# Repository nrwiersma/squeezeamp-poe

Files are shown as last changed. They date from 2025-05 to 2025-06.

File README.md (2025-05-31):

# SqueezeAMP PoE




`SqueezeAMP PoE` is an amplifier driven by an ESP32 designed to run [squeezelite-esp32](https://github.com/sle118/squeezelite-esp32), powered by PoE++.

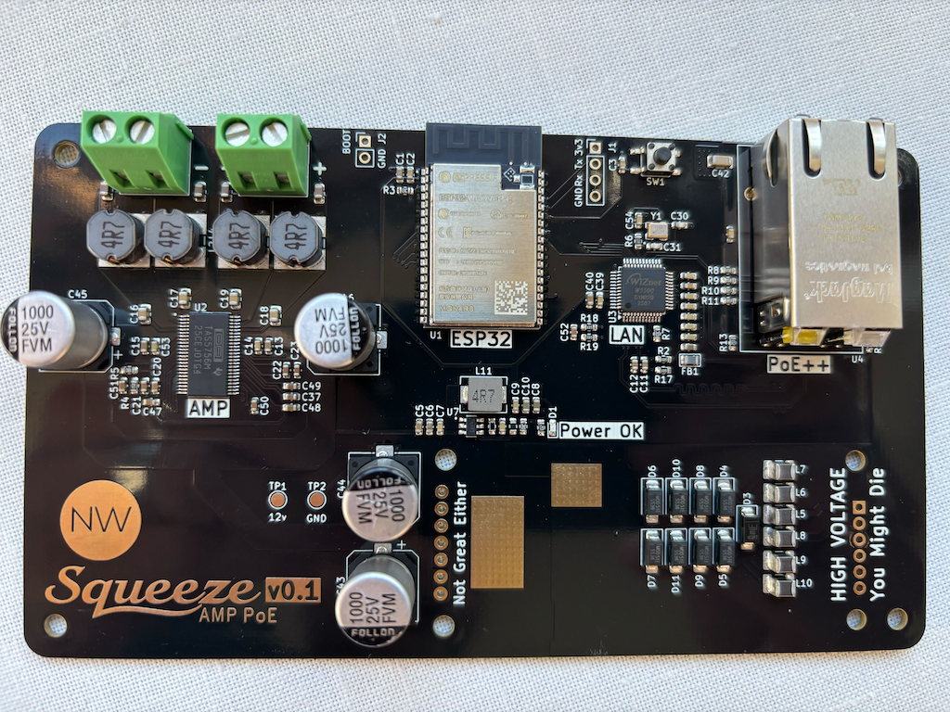
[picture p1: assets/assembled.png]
board image


Features:

* Power over Ethernet 802.3bt 60W (PoE++)
* ESP32 WROOM 4MB Flash 8MB PSRAM
* TAS5756 Amplifier capable of driving stereo 30W 8Ohm speakers

## Why

The position of speakers is often not optimal for WiFi, leading to unreliable music streaming. Adding 100Mb ethernet allows
more reliable connections with ample bandwidth. Given an ethernet connection, PoE is able to provide power for the device.

The schematic is inspired by the [SqueezeAMPagain](https://github.com/hallo-alex/SqueezeAMPagain).

## Configuration

Install [squeezelite-esp32](https://github.com/sle118/squeezelite-esp32). The simplest method is to use the [installer](https://sle118.github.io/squeezelite-esp32-installer/).

Set the following configuration via the NVS Editor to configure:

dac_config: `model=TAS57xx,bck=33,ws=25,do=32,sda=27,scl=26,mute=4:0`
eth_config: `model=w5500,cs=15,speed=20000000,intr=18,rst=19`
spi_config: `mosi=13,clk=14,host=1,miso=12,dc=-1`
set_GPIO:   `2=spkfault`

## PCB Fabrication and Assembly by PCBWay

I am proudly sponsored by [PCBWay](https://www.pcbway.com/), a leading manufacturer specializing in PCB prototyping, 
low-volume production, and PCB Assembly services. Thanks to PCBWay’s sponsorship, I was able to fabricate and assemble 
my PCBs with high precision and quality. Their advanced manufacturing capabilities ensured that our design was 
translated into a robust and functional product.

[//]: # (![board image]&#40;assets/pcb.png&#41;)

### Why PCBWay?

PCBWay offers:

* **High-quality PCB fabrication** with multiple layer options, surface finishes, and material choices.
* **Fast turnaround times** to meet project deadlines efficiently.
* **Affordable pricing** for both prototyping and mass production.
* **Reliable PCB assembly services**, including SMT, through-hole, and mixed assembly.
* **Exceptional customer support** and a user-friendly ordering platform.

### Get Your Own PCBs from PCBWay

I highly recommend PCBWay for all your PCB fabrication and assembly needs. Their dedication to quality and customer 
satisfaction makes them an ideal partner for your projects. If you're looking for a trusted partner for PCB fabrication 
and assembly, check out PCBWay for your next project.

Special thanks to PCBWay for their generous support!

## Changelog

#### v0.1.0

* Initial schematic and board

#### v0.1.1

* Fixed W5500 crystal clock not being enabled

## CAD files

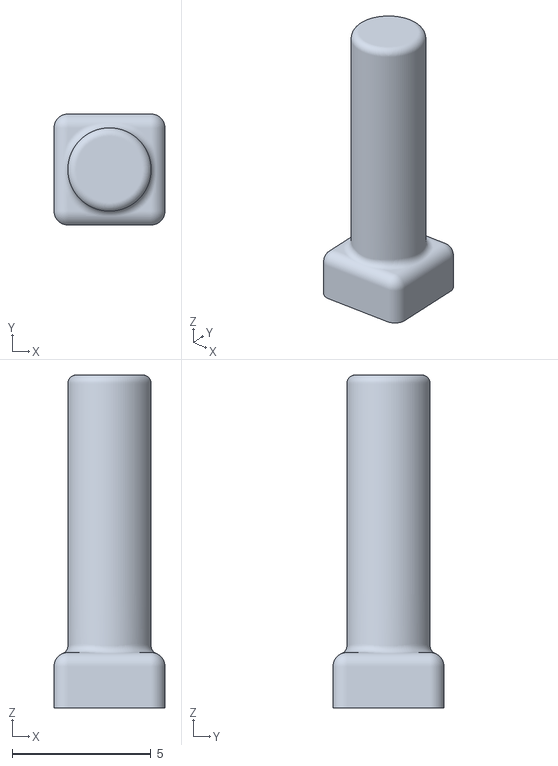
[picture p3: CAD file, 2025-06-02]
models/Button.stl
4.00 x 4.00 x 12.0

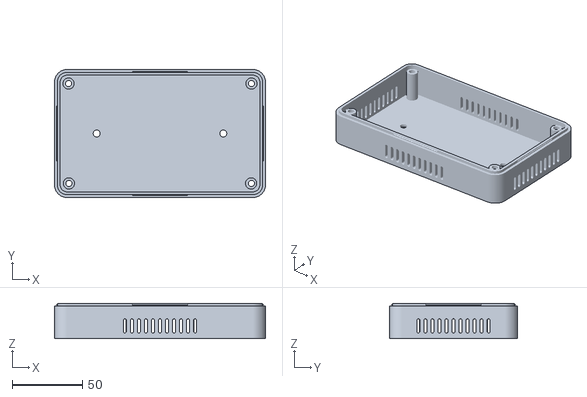
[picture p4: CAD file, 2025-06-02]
models/Base.stl
150.0 x 91.0 x 25.0

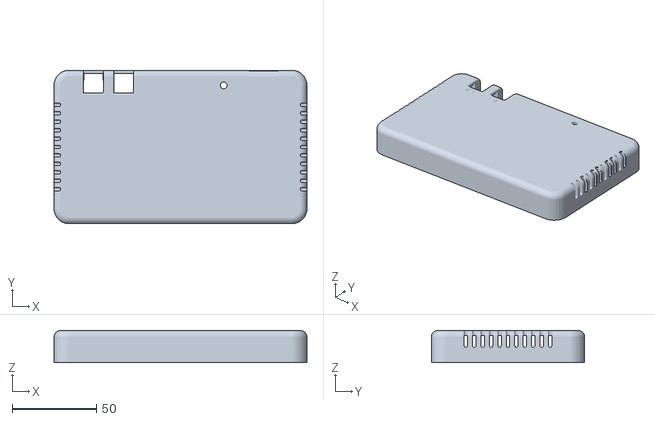
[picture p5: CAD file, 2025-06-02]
models/Lid.stl
150.0 x 91.0 x 19.0

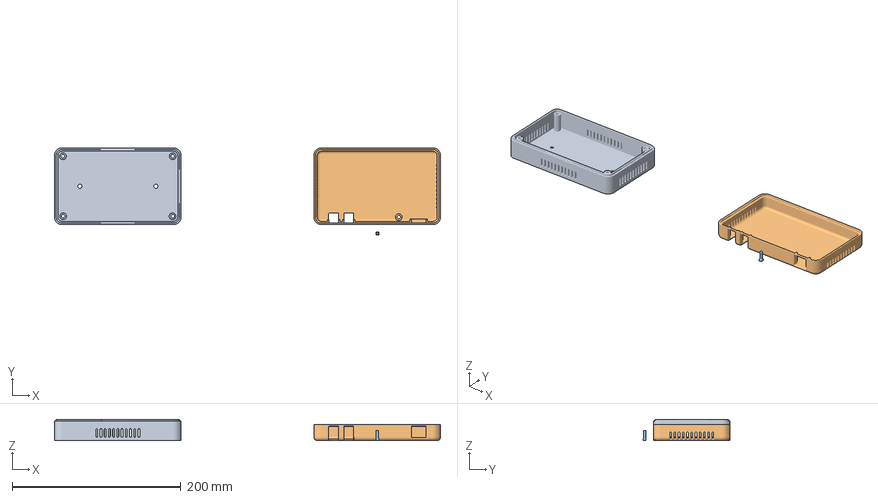
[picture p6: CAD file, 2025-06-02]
models/SqueezeAMPPoE.3mf
457.2 x 103.4 x 25.0 mm
Base.stl
Lid.stl
Button.stl

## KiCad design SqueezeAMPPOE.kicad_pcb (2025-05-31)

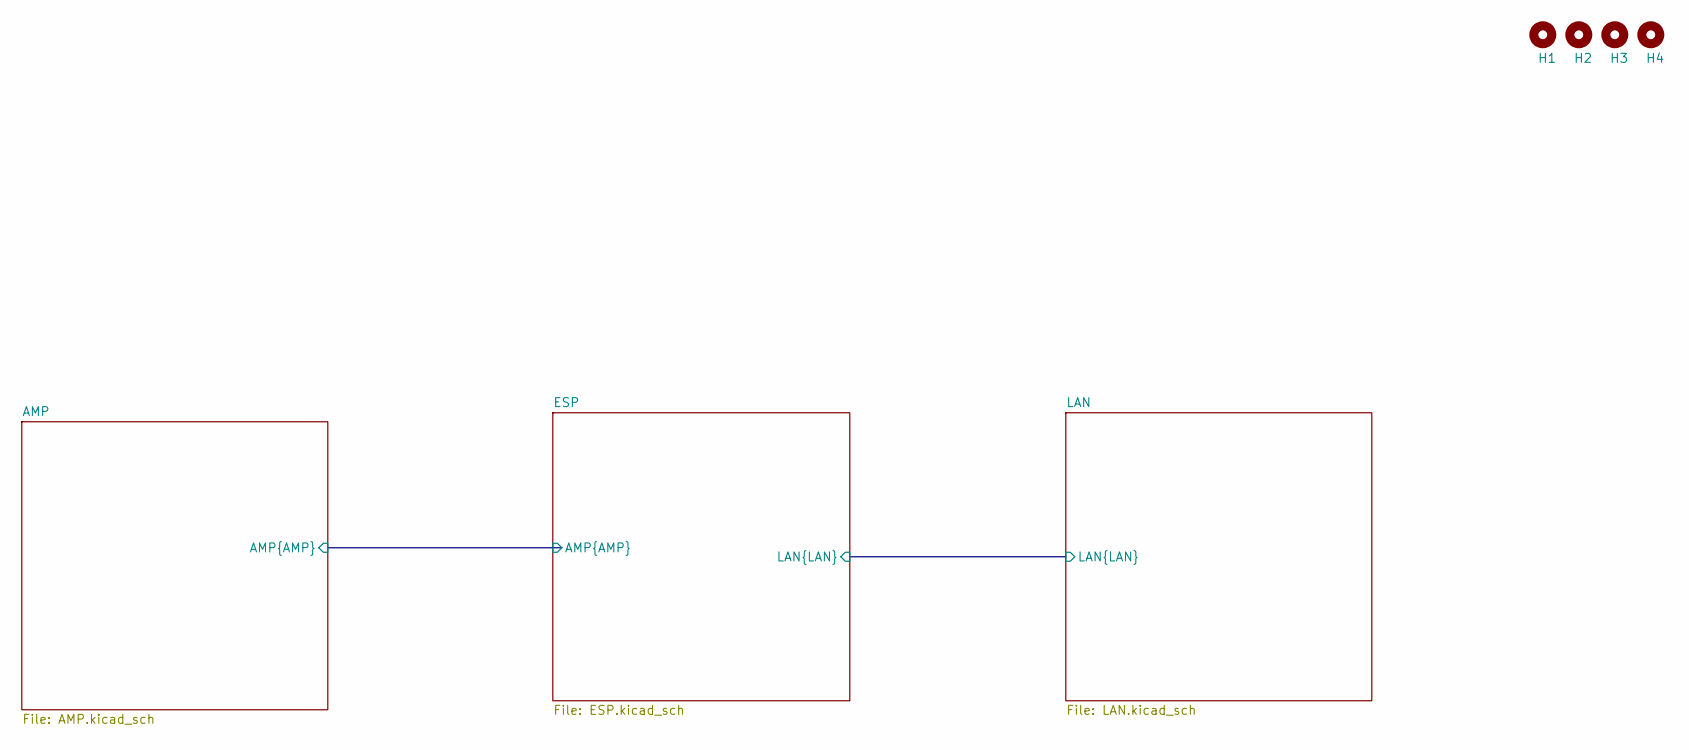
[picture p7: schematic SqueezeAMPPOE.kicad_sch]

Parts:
H1, H2, H3, H4: MountingHole; MountingHole_3.2mm_M3

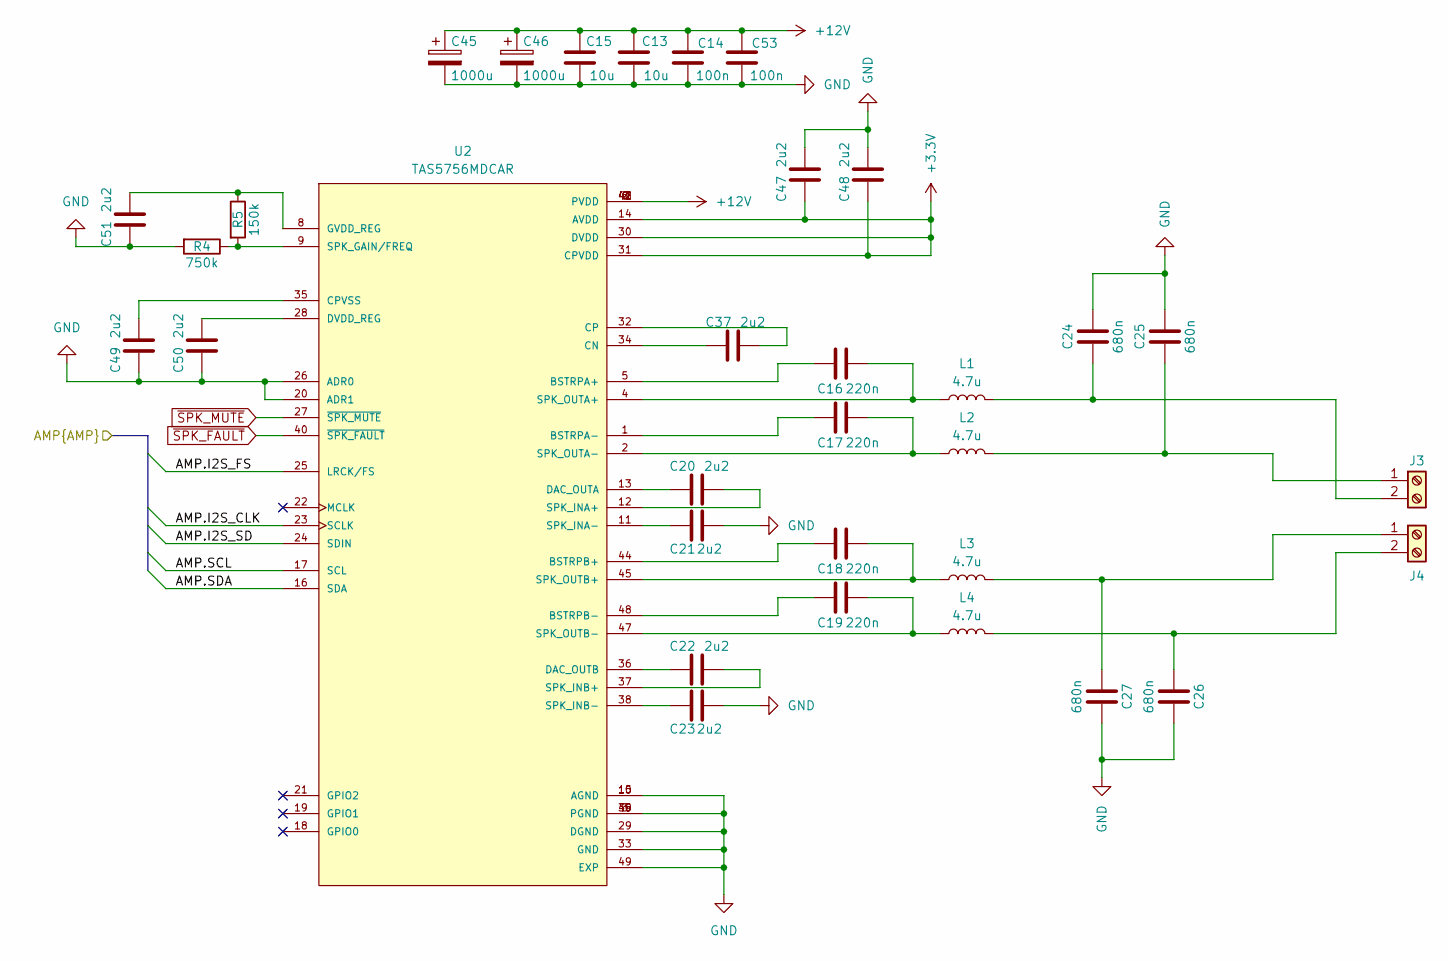
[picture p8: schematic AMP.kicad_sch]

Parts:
C13, C15: 10u; C_0603_1608Metric; MPN CL10A106MA8NRNC; JLCPCB Part # C96446
C14, C53: 100n; C_0603_1608Metric; MPN CL10B104KB8NNNC; JLCPCB Part # C1591
C16, C17, C18, C19: 220n; C_0805_2012Metric; MPN CL21B224KBFNNNE; JLCPCB Part # C5378
C20, C21, C22, C23, C37, C47, C48, C49, C50, C51: 2u2; C_0603_1608Metric; MPN CL10A225KA8NNNC; JLCPCB Part # C57895
C24, C25, C26, C27: 680n; C_0805_2012Metric; MPN CC0805KKX7R9BB684; JLCPCB Part # C107133
C45, C46: 1000u; CP_Elec_10x12.5; MPN EFVM025ADA102M10C0; JLCPCB Part # C22387800
J3, J4: Screw_Terminal_01x02; TerminalBlock_Phoenix_MKDS-1,5-2-5.08_1x02_P5.08mm_Horizont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; MPN 1715721; JLCPCB Part # C480516
L1, L2, L3, L4: 4.7u; L_Ferrocore_DLG-0703; MPN SM7850-4R7MT; JLCPCB Part # C52377
R4: 750k; R_0603_1608Metric; MPN RC0603FR-07750KL; JLCPCB Part # C137684
R5: 150k; R_0603_1608Metric; MPN RC0603FR-07150KL; JLCPCB Part # C114660
U2: TAS5756MDCAR; SOP50P810X120-49N; MPN TAS5756MDCAR; JLCPCB Part # C2867541

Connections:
+3.3V: C47.1, C48.1, U2.14 (AVDD), U2.30 (DVDD), U2.31 (CPVDD); also elsewhere on the board
+12V: C13.2, C14.2, C15.2, C45.1, C46.1, C53.2, U2.6 (PVDD), U2.7 (PVDD), U2.41 (PVDD), U2.42 (PVDD), U2.43 (PVDD); also elsewhere on the board
/AMP/AMP.I2S_CLK: U2.23 (SCLK); also elsewhere on the board
/AMP/AMP.I2S_FS: U2.25 (LRCK/FS); also elsewhere on the board
/AMP/AMP.I2S_SD: U2.24 (SDIN); also elsewhere on the board
/AMP/AMP.SCL: U2.17 (SCL); also elsewhere on the board
/AMP/AMP.SDA: U2.16 (SDA); also elsewhere on the board
GND: C13.1, C14.1, C15.1, C21.2, C23.2, C24.2, C25.2, C26.2, C27.2, C45.2, C46.2, C47.2, C48.2, C49.1, C50.1, C51.1, C53.1, R4.2, U2.3 (PGND), U2.10 (AGND), U2.15 (AGND), U2.20 (ADR1), U2.26 (ADR0), U2.29 (DGND), U2.33 (GND), U2.39 (PGND), U2.46 (PGND), U2.49 (EXP); also elsewhere on the board
unnamed: C25.1, J3.1, L2.2
unnamed: C24.1, J3.2, L1.2
unnamed: C27.1, J4.1, L3.2
unnamed: C26.1, J4.2, L4.2
unnamed: C16.1, U2.5 (BSTRPA+)
unnamed: C17.1, U2.1 (BSTRPA-)
unnamed: C18.1, U2.44 (BSTRPB+)
unnamed: C19.1, U2.48 (BSTRPB-)
unnamed: C37.1, U2.34 (CN)
unnamed: C37.2, U2.32 (CP)
unnamed: C49.2, U2.35 (CPVSS)
unnamed: C20.1, U2.13 (DAC_OUTA)
unnamed: C22.1, U2.36 (DAC_OUTB)
unnamed: C50.2, U2.28 (DVDD_REG)
unnamed: C51.2, R5.1, U2.8 (GVDD_REG)
unnamed: R4.1, R5.2, U2.9 (SPK_GAIN/FREQ)
unnamed: C20.2, U2.12 (SPK_INA+)
unnamed: C21.1, U2.11 (SPK_INA-)
unnamed: C22.2, U2.37 (SPK_INB+)
unnamed: C23.1, U2.38 (SPK_INB-)
unnamed: C16.2, L1.1, U2.4 (SPK_OUTA+)
unnamed: C17.2, L2.1, U2.2 (SPK_OUTA-)
unnamed: C18.2, L3.1, U2.45 (SPK_OUTB+)
unnamed: C19.2, L4.1, U2.47 (SPK_OUTB-)
~SPK_FAULT: U2.40 (~SPK_FAULT); also elsewhere on the board
~SPK_MUTE: U2.27 (~SPK_MUTE); also elsewhere on the board

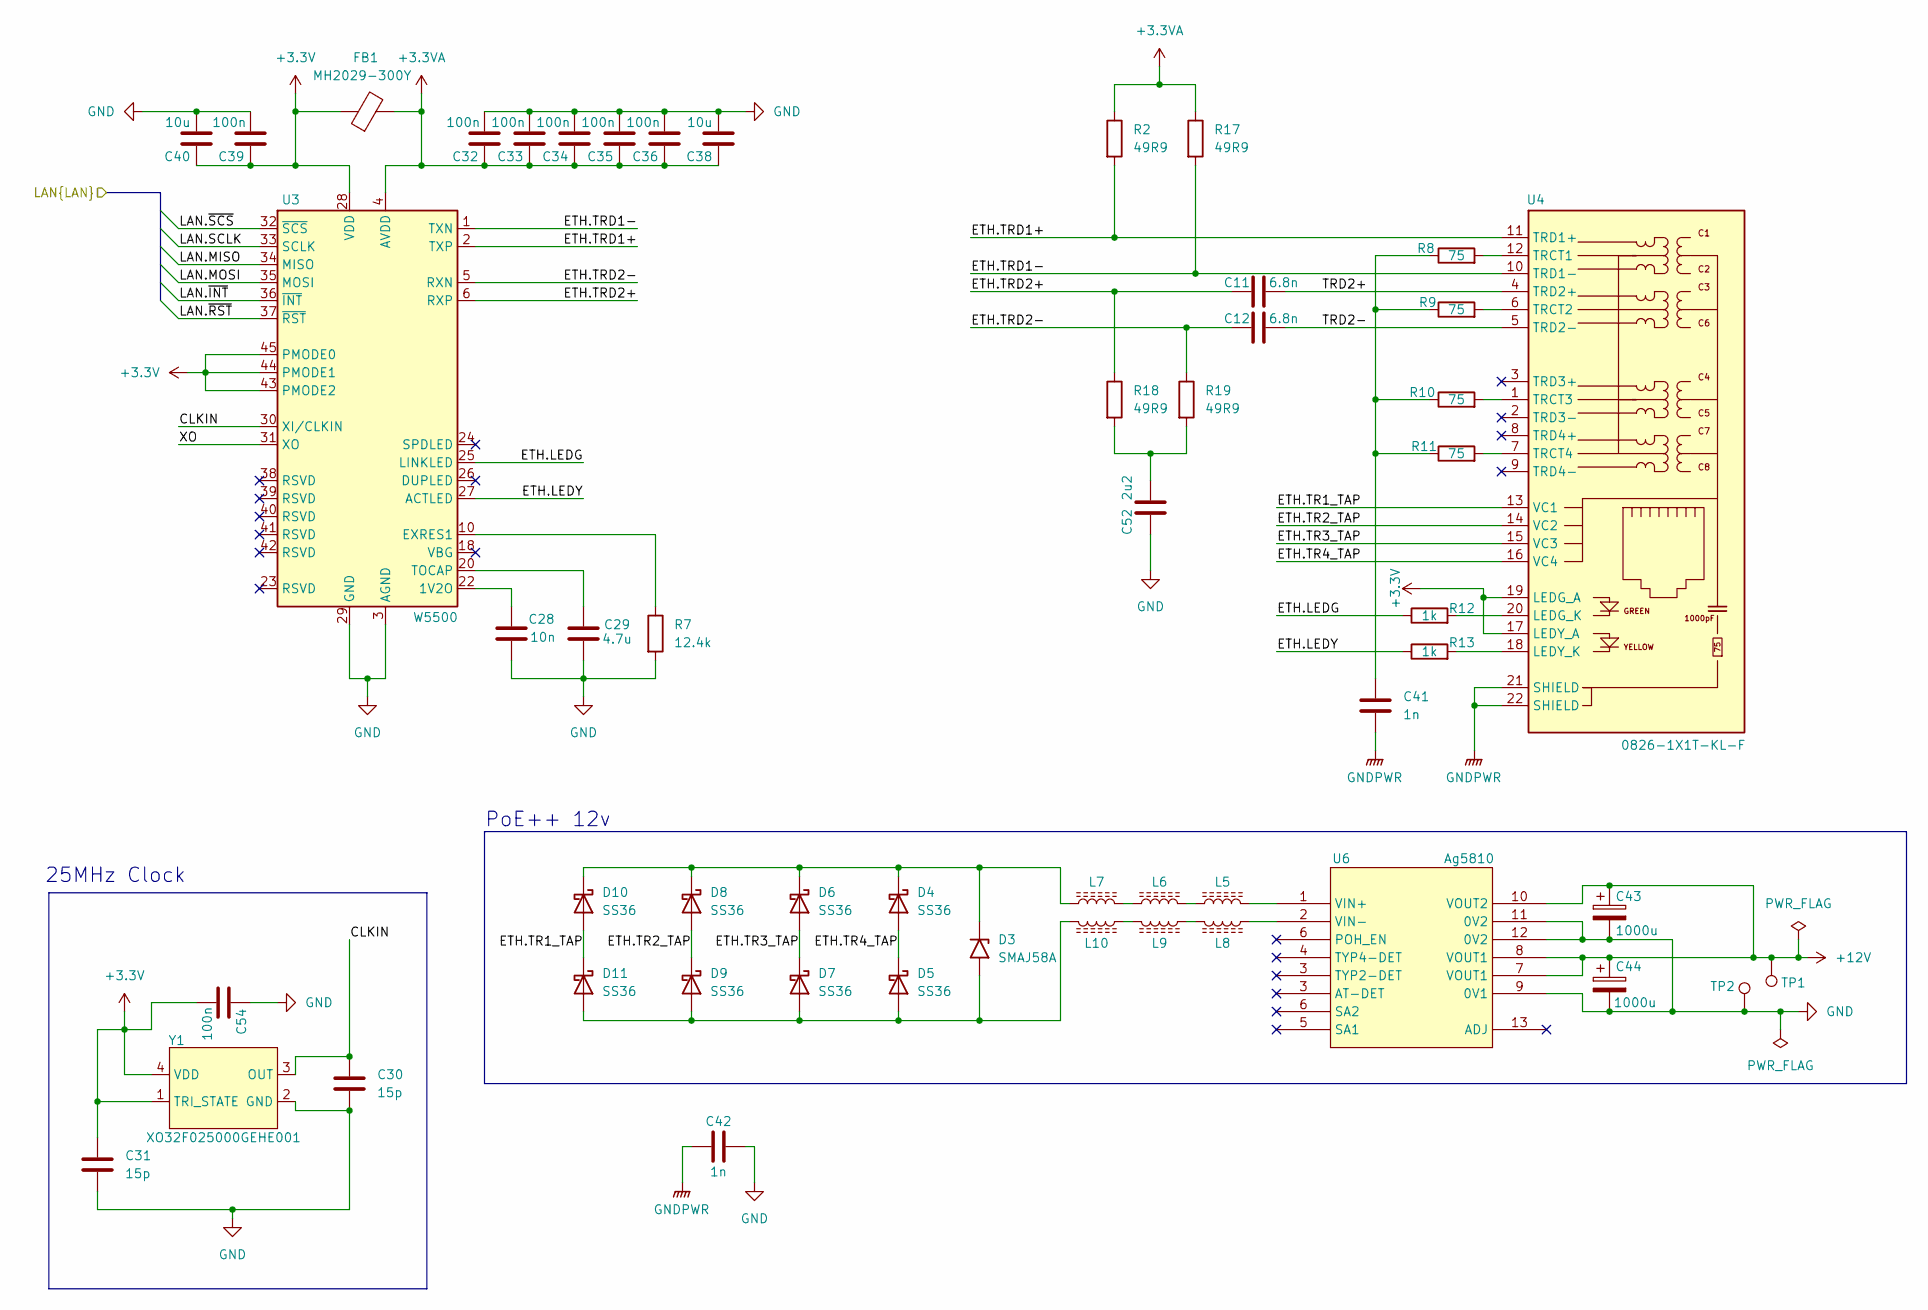
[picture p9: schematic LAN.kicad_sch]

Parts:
C11, C12: 6.8n; C_0603_1608Metric; MPN C1608C0G2A682J080AC; JLCPCB Part # C2183110
C28: 10n; C_0603_1608Metric; MPN CL10B103KB8NNNC; JLCPCB Part # C1589
C29: 4.7u; C_0603_1608Metric; MPN CL10A475KP8NNNC; JLCPCB Part # C1705
C30, C31: 15p; C_0603_1608Metric; MPN CL10C150JB8NNNC; JLCPCB Part # C1644
C32, C33, C34, C35, C36, C39, C54: 100n; C_0603_1608Metric; MPN CL10B104KB8NNNC; JLCPCB Part # C1591
C38, C40: 10u; C_0603_1608Metric; MPN CL10A106MA8NRNC; JLCPCB Part # C96446
C41: 1n; C_0603_1608Metric; MPN CL10B102KB8NNNC; JLCPCB Part # C1588
C42: 1n; C_1206_3216Metric; MPN CC1206KKX7RDBB102; JLCPCB Part # C23631
C43, C44: 1000u; CP_Elec_10x12.5; MPN EFVM025ADA102M10C0; JLCPCB Part # C22387800
C52: 2u2; C_0603_1608Metric; MPN CL10A225KA8NNNC; JLCPCB Part # C57895
D3: SMAJ58A; D_SMA; MPN SMAJ58A; JLCPCB Part # C151246
D4, D5, D6, D7, D8, D9, D10, D11: SS36; D_SMA; MPN SS36; JLCPCB Part # C16015
FB1: MH2029-300Y; L0805; MPN MH2029-300Y; JLCPCB Part # C840593
L5, L6, L7, L8, L9, L10: FBMH3225HM102NT; L_1210; MPN FBMH3225HM102NT; JLCPCB Part # C21520
R2, R17, R18, R19: 49R9; R_0603_1608Metric; MPN RC0603FR-0749R9L; JLCPCB Part # C114625
R7: 12.4k; R_0603_1608Metric; MPN RC0603FR-0712K4L; JLCPCB Part # C137798
R8, R9, R10, R11: 75; R_0603_1608Metric; MPN RC0603FR-0775RL; JLCPCB Part # C112309
R12, R13: 1k; R_0603_1608Metric; MPN RC0603JR-071KL; JLCPCB Part # C14676
TP1, TP2: TestPoint; TestPoint_Pad_D2.0mm
U3: W5500; LQFP-48_7x7mm_P0.5mm; MPN W5500; JLCPCB Part # C32843
U4: 0826-1X1T-KL-F; CONN_0826-1X1T-HS-F_BEL; MPN 0826-1X1T-KL-F; JLCPCB Part # C3179906
U6: Ag5810; Converter_DCDC_Silvertel_Ag5810; MPN Ag5810
Y1: XO32F025000GEHE001; SMD3225-4P; MPN XO32F025000GEHE001; JLCPCB Part # C20607963

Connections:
+3.3V: C31.2, C39.1, C40.1, C54.2, FB1.1, U3.28 (VDD), U3.43 (PMODE2), U3.44 (PMODE1), U3.45 (PMODE0), U4.17 (LEDY_A), U4.19 (LEDG_A), Y1.1 (TRI_STATE), Y1.4 (VDD); also elsewhere on the board
+3.3VA: C32.1, C33.1, C34.1, C35.1, C36.1, C38.1, FB1.2, R2.1, R17.1, U3.4 (AVDD), U3.8 (AVDD), U3.11 (AVDD), U3.15 (AVDD), U3.17 (AVDD), U3.21 (AVDD)
+12V: C43.1, C44.1, TP1.1, U6.7 (VOUT1), U6.8 (VOUT1), U6.10 (VOUT2); also elsewhere on the board
/ESP/LAN.MISO: U3.34 (MISO); also elsewhere on the board
/ESP/LAN.MOSI: U3.35 (MOSI); also elsewhere on the board
/ESP/LAN.SCLK: U3.33 (SCLK); also elsewhere on the board
/ESP/LAN.~INT: U3.36 (~INT); also elsewhere on the board
/ESP/LAN.~RST: U3.37 (~RST); also elsewhere on the board
/ESP/LAN.~SCS: U3.32 (~SCS); also elsewhere on the board
/LAN/CLKIN: C30.1, U3.30 (XI/CLKIN), Y1.3 (OUT)
/LAN/ETH.LEDG: R12.1, U3.25 (LINKLED)
/LAN/ETH.LEDY: R13.1, U3.27 (ACTLED)
/LAN/ETH.TR1_TAP: D10.2 (A), D11.1 (K), U4.13 (VC1)
/LAN/ETH.TR2_TAP: D8.2 (A), D9.1 (K), U4.14 (VC2)
/LAN/ETH.TR3_TAP: D6.2 (A), D7.1 (K), U4.15 (VC3)
/LAN/ETH.TR4_TAP: D4.2 (A), D5.1 (K), U4.16 (VC4)
/LAN/ETH.TRD1+: R2.2, U3.2 (TXP), U4.11 (TRD1+)
/LAN/ETH.TRD1-: R17.2, U3.1 (TXN), U4.10 (TRD1-)
/LAN/ETH.TRD2+: C11.1, R18.1, U3.6 (RXP)
/LAN/ETH.TRD2-: C12.1, R19.1, U3.5 (RXN)
/LAN/TRD2+: C11.2, U4.4 (TRD2+)
/LAN/TRD2-: C12.2, U4.5 (TRD2-)
/LAN/XO: U3.31 (XO)
GND: C28.2, C29.2, C30.2, C31.1, C32.2, C33.2, C34.2, C35.2, C36.2, C38.2, C39.2, C40.2, C42.2, C43.2, C44.2, C52.1, C54.1, R7.2, TP2.1, U3.3 (AGND), U3.9 (AGND), U3.14 (AGND), U3.16 (AGND), U3.19 (AGND), U3.29 (GND), U3.48 (AGND), U6.9 (0V1), U6.11 (0V2), U6.12 (0V2), Y1.2 (GND); also elsewhere on the board
GNDPWR: C41.2, C42.1, U4.21 (SHIELD), U4.22 (SHIELD)
unnamed: C41.1, R8.1, R9.1, R10.1, R11.1
unnamed: C52.2, R18.2, R19.2
unnamed: D3.1 (A1), D4.1 (K), D6.1 (K), D8.1 (K), D10.1 (K), L7.1
unnamed: D3.2 (A2), D5.2 (A), D7.2 (A), D9.2 (A), D11.2 (A), L10.2
unnamed: L5.1, L6.2
unnamed: L6.1, L7.2
unnamed: L8.2, L9.1
unnamed: L9.2, L10.1
unnamed: C28.1, U3.22 (1V2O)
unnamed: R7.1, U3.10 (EXRES1)
unnamed: C29.1, U3.20 (TOCAP)
unnamed: R12.2, U4.20 (LEDG_K)
unnamed: R13.2, U4.18 (LEDY_K)
unnamed: R8.2, U4.12 (TRCT1)
unnamed: R9.2, U4.6 (TRCT2)
unnamed: R10.2, U4.1 (TRCT3)
unnamed: R11.2, U4.7 (TRCT4)
unnamed: L5.2, U6.1 (VIN+)
unnamed: L8.1, U6.2 (VIN-)

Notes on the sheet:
PoE++ 12v
25MHz Clock

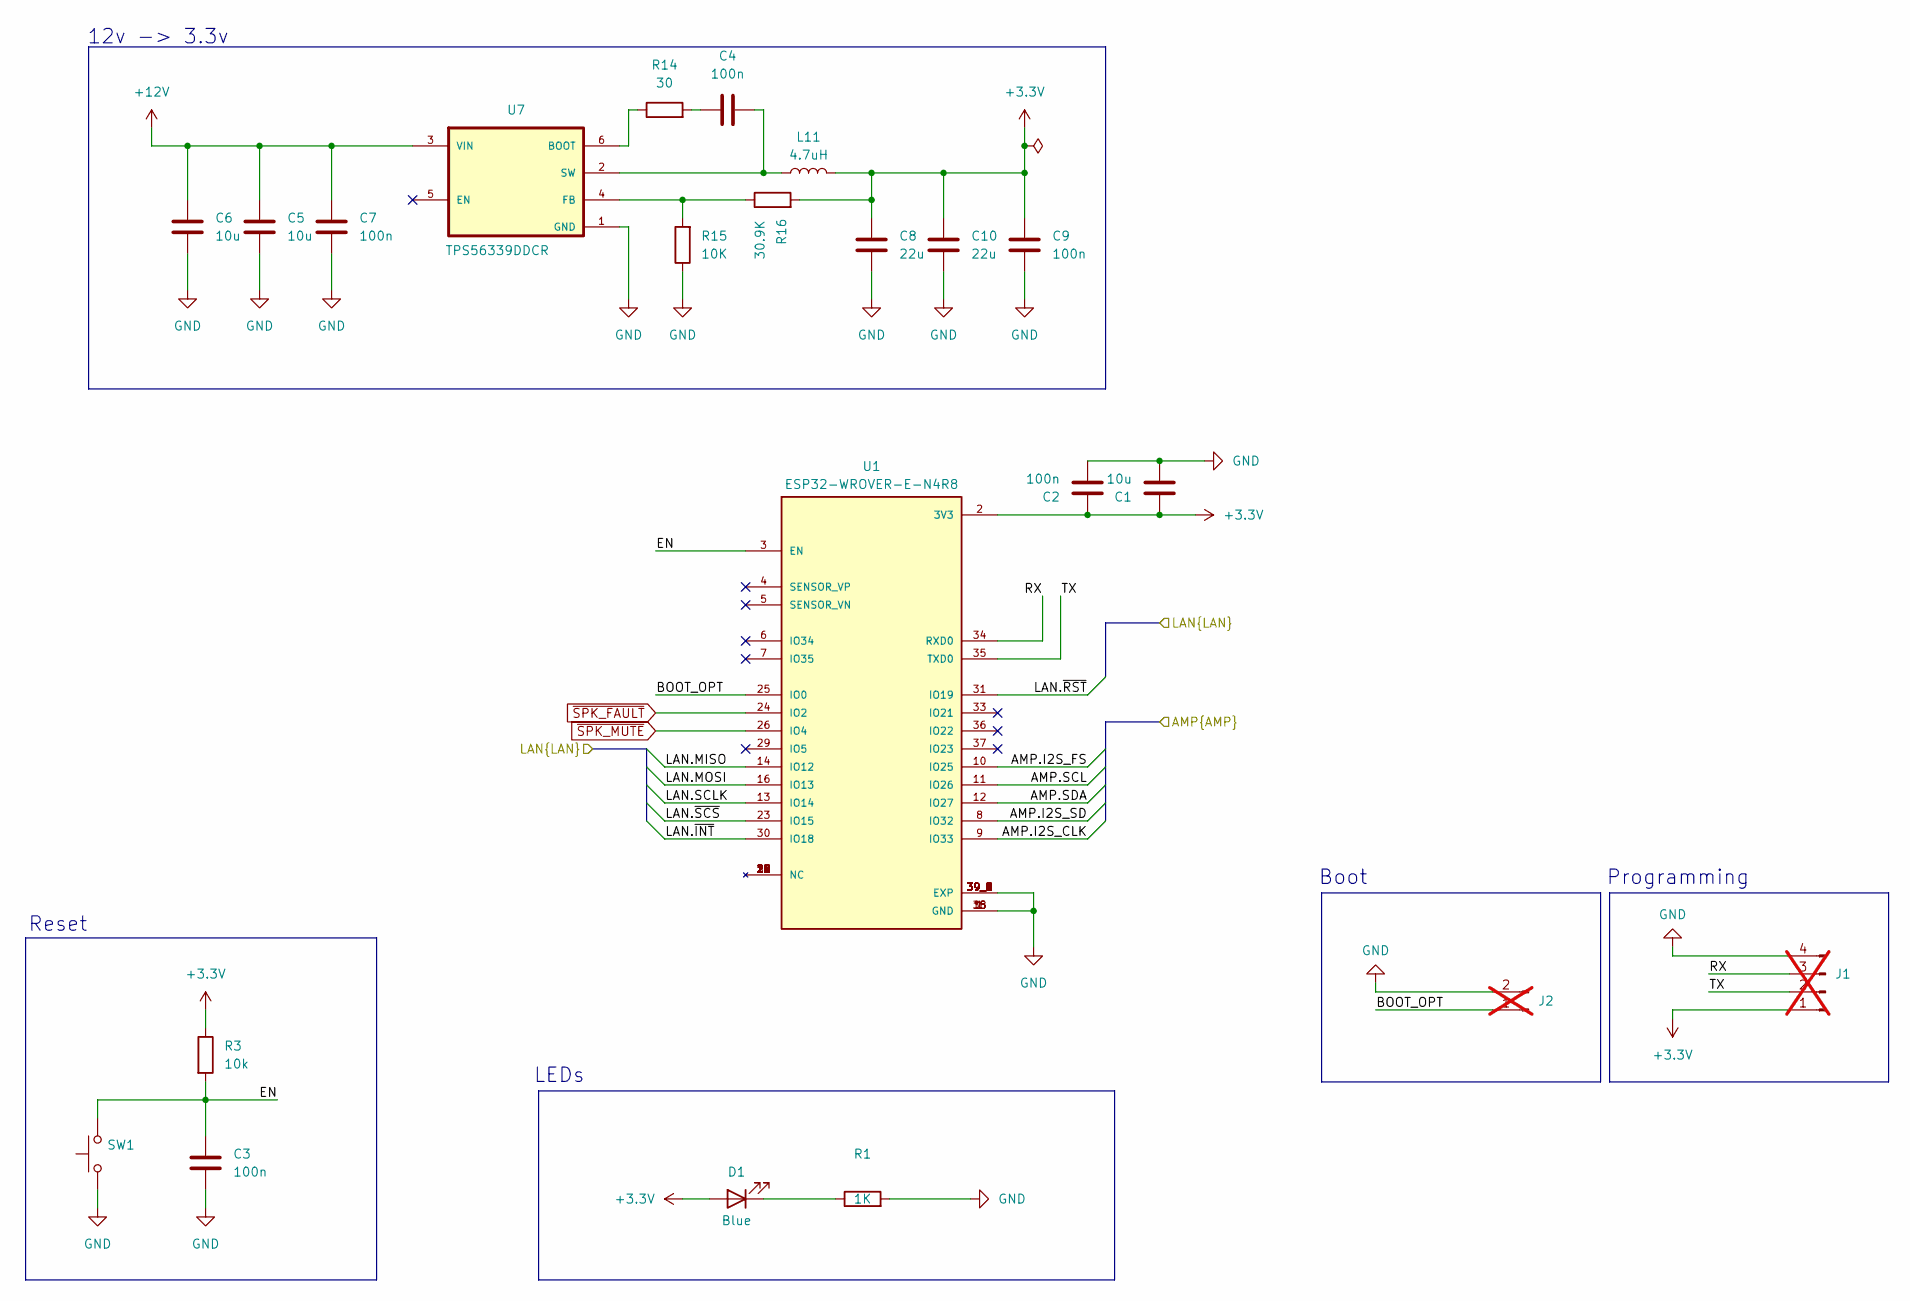
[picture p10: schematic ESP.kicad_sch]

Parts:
C1, C5, C6: 10u; C_0603_1608Metric; MPN CL10A106MA8NRNC; JLCPCB Part # C96446
C2, C3, C4, C7, C9: 100n; C_0603_1608Metric; MPN CL10B104KB8NNNC; JLCPCB Part # C1591
C8, C10: 22u; C_0603_1608Metric; MPN CL10A226MQ8NRNC; JLCPCB Part # C59461
D1: Blue; LED_0603_1608Metric; MPN LTST-C191TBKT; JLCPCB Part # C99290
J1: Conn_01x04_Pin; PinHeader_1x04_P2.54mm_Vertical; not fitted
J2: Conn_01x02_Pin; PinHeader_1x02_P2.54mm_Vertical; not fitted
L11: 4.7uH; YSPI0530; MPN YSPI0530-4R7M; JLCPCB Part # C351098
R1: 1K; R_0603_1608Metric; MPN ERJ3GEYJ102V; JLCPCB Part # C180848
R3: 10k; R_0603_1608Metric; MPN CR0603AFX-1002EAS; JLCPCB Part # C2091877
R14: 30; R_0603_1608Metric; MPN ERJ3EKF30R0V; JLCPCB Part # C403150
R15: 10K; R_0603_1608Metric; MPN CR0603AFX-1002EAS; JLCPCB Part # C2091877
R16: 30.9K; R_0603_1608Metric; MPN ERJ3EKF3092V; JLCPCB Part # C400664
SW1: SW_Push; K2-1109SP-B4SA-01; MPN K2-1109SP-B4SA-01; JLCPCB Part # C92571
U1: ESP32-WROVER-E-N4R8; XCVR_ESP32-WROVER-E-N4R8; MPN ESP32-WROVER-E-N4R8; JLCPCB Part # C967023
U7: TPS56339DDCR; MPN TPS56339DDCR; JLCPCB Part # C2071106

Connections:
+3.3V: C1.1, C2.1, C8.2, C9.2, C10.2, D1.2 (A), J1.1, L11.2, R3.1, R16.2, U1.2 (3V3); also elsewhere on the board
+12V: C5.2, C6.2, C7.2, U7.3 (VIN); also elsewhere on the board
/AMP/AMP.I2S_CLK: U1.9 (IO33); also elsewhere on the board
/AMP/AMP.I2S_FS: U1.10 (IO25); also elsewhere on the board
/AMP/AMP.I2S_SD: U1.8 (IO32); also elsewhere on the board
/AMP/AMP.SCL: U1.11 (IO26); also elsewhere on the board
/AMP/AMP.SDA: U1.12 (IO27); also elsewhere on the board
/ESP/BOOT_OPT: J2.1, U1.25 (IO0)
/ESP/EN: C3.1, R3.2, SW1.2, U1.3 (EN)
/ESP/LAN.MISO: U1.14 (IO12); also elsewhere on the board
/ESP/LAN.MOSI: U1.16 (IO13); also elsewhere on the board
/ESP/LAN.SCLK: U1.13 (IO14); also elsewhere on the board
/ESP/LAN.~INT: U1.30 (IO18); also elsewhere on the board
/ESP/LAN.~RST: U1.31 (IO19); also elsewhere on the board
/ESP/LAN.~SCS: U1.23 (IO15); also elsewhere on the board
/ESP/RX: J1.3, U1.34 (RXD0)
/ESP/TX: J1.2, U1.35 (TXD0)
GND: C1.2, C2.2, C3.2, C5.1, C6.1, C7.1, C8.1, C9.1, C10.1, J1.4, J2.2, R1.2, R15.1, SW1.1, U1.1 (GND), U1.15 (GND), U1.38 (GND), U1.39_1 (EXP), U1.39_2 (EXP), U1.39_3 (EXP), U1.39_4 (EXP), U1.39_5 (EXP), U1.39_6 (EXP), U1.39_7 (EXP), U1.39_8 (EXP), U1.39_9 (EXP), U7.1 (GND); also elsewhere on the board
unnamed: C4.1, R14.2
unnamed: D1.1 (K), R1.1
unnamed: R14.1, U7.6 (BOOT)
unnamed: R15.2, R16.1, U7.4 (FB)
unnamed: C4.2, L11.1, U7.2 (SW)
~SPK_FAULT: U1.24 (IO2); also elsewhere on the board
~SPK_MUTE: U1.26 (IO4); also elsewhere on the board

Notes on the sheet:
Boot
LEDs
12v -> 3.3v
Reset
Programming

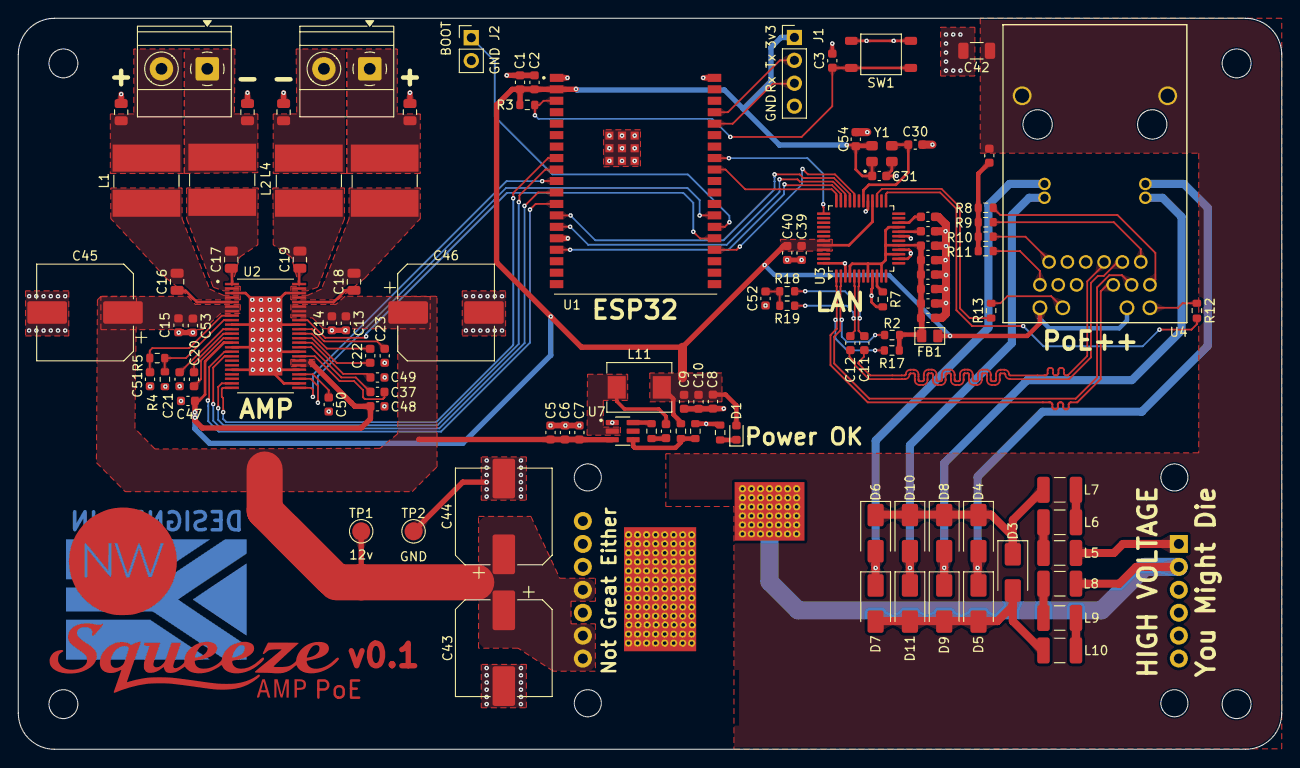
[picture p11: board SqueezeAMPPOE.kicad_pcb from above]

Board: 4 copper layers, 140.0 x 81.0 mm, 112 parts (1 on the bottom side), 83 nets.

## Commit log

2025-05-08 feat: initial board (#1)
    [AMP.kicad_sch, ESP.kicad_sch, LAN.kicad_sch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]
2025-05-31 fix: crystal clock enable pin to 3v3
    [LAN.kicad_sch, SqueezeAMPPOE.kicad_pcb]
2025-06-02 feat: add case models (#2)
    [Base.stl, Button.stl, Lid.stl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]
2026-10-26 fix: specify 25V rating on caps on the 12V rail (#3)

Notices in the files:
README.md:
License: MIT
